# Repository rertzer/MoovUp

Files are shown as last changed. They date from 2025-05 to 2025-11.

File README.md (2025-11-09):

# MoovUp

MoovUp is a 3D printed robotic arm based on the [InMoov](inmoov.fr) project.
Mounted on a wooden crate, it has eight degrees of freedom and each finger is equipped with a pressure sensor.
The thumb's position has been redesigned to give a grasping function.
The arm is driven by an ATMega2560 microcontroler programmed in bare-metal C++.
Communication and control are implemented via a UART serial interface.

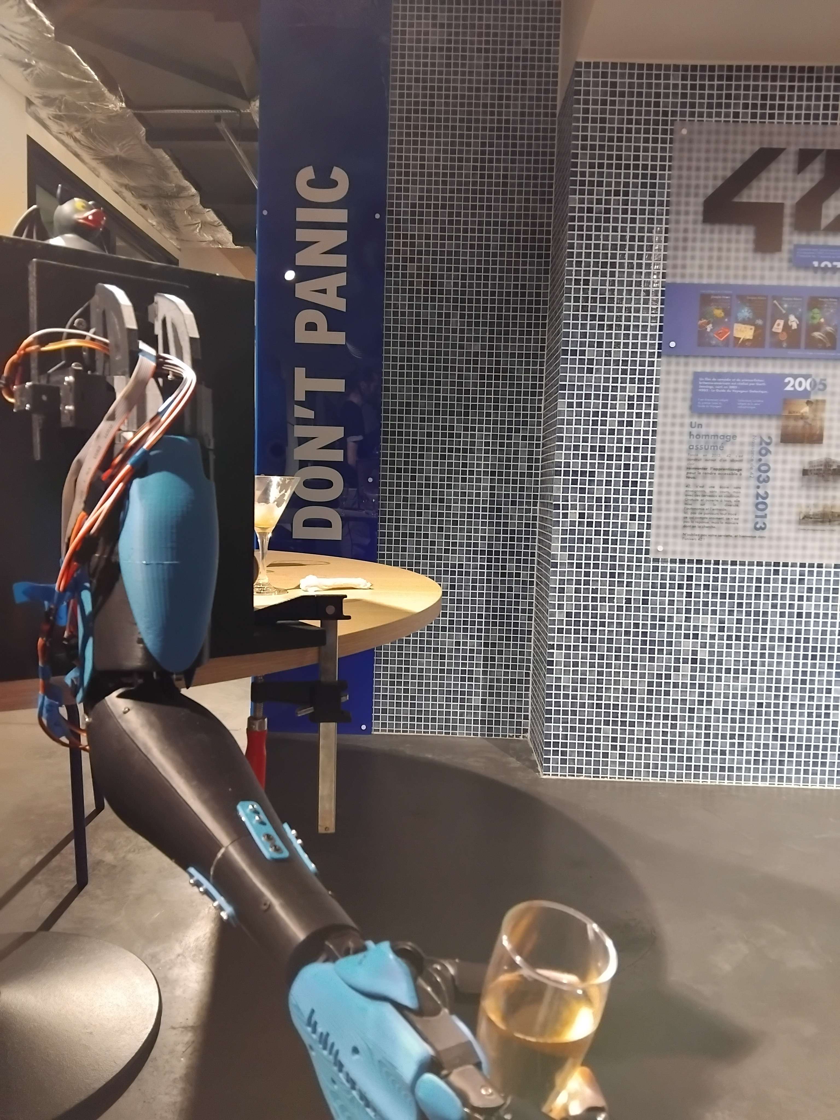
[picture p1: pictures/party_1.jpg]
MoovUp toasting


# UART Commands

- shoulder left
- shoulder right
- wrist left
- wrist right
- hand open
- hand close
- hand grab
- thumb open
- thumb close
- index open
- index close
- finger open

# pinout

| ArduinoMega pin | ATmega 2560 port | timer | kind | usage |
| :---: | :---: | :---: | :----- | :--- |
| A1 | PF1 |  -- | sensor | thumb |
| A2 | PF2 |  -- | sensor | index |
| A3 | PF3 |  -- | sensor | middle |
| A4 | PF4 |  -- | sensor | ring |
| A5 | PF5 |  -- | sensor | pinky |
| D2 | PE4 | OC3B  | motor  | thumb |
| D3 | PE5 | OC3C  | motor  | index |
| D5 | PE3 | OC3A  | motor  | middle |
| D6 | PH3 | OC4A  | motor  | ring |
| D7 | PH4 | OC4B  | motor  | pinky |
| D8 | PH5 | OC4C  | motor  | wrist |
| D11 | PB5 | OC1A  | motor  | elbow |
| D12 | PB6 | OC1B  | motor  | shoulder |

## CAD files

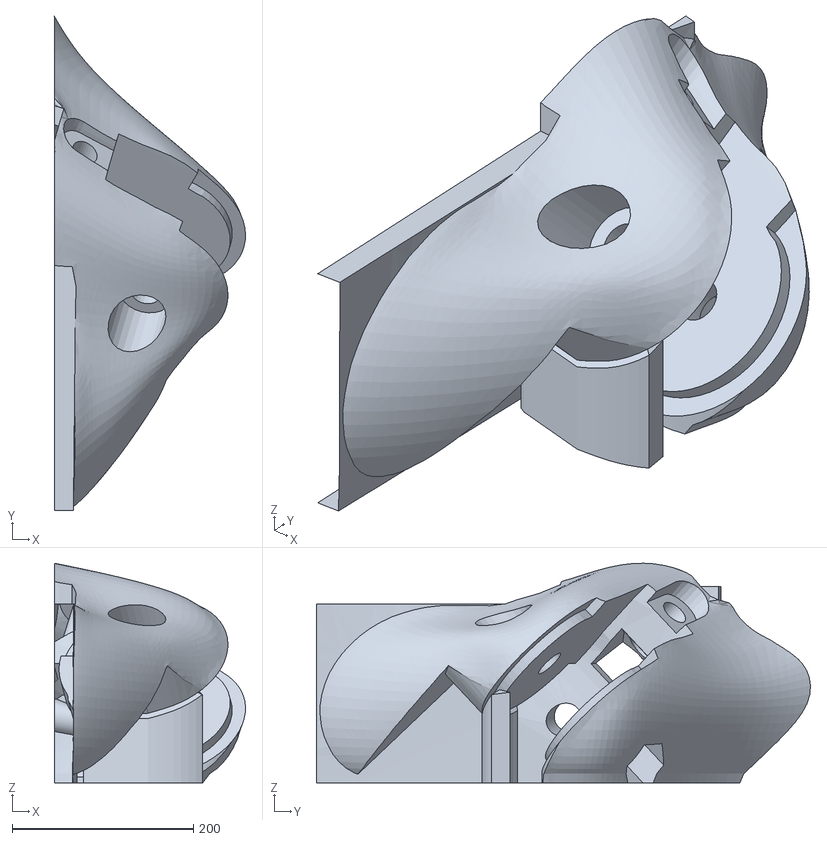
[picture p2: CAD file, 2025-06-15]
fusion_models/blender/thumb.stl
210.6 x 544.6 x 242.1

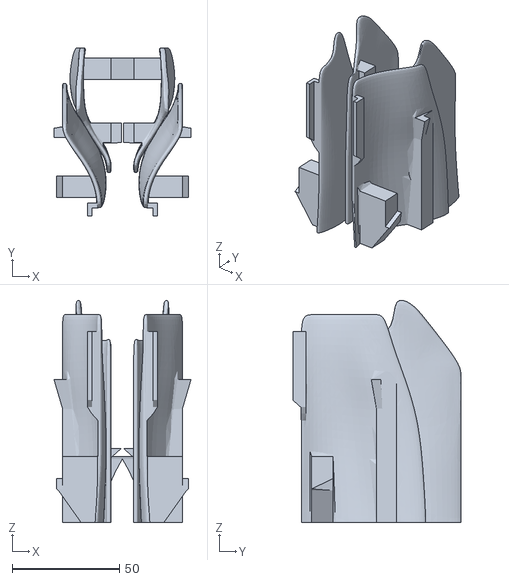
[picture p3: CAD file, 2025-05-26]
toPrint/bicep/color/armtopcover3.stl
63.9 x 78.6 x 103.5

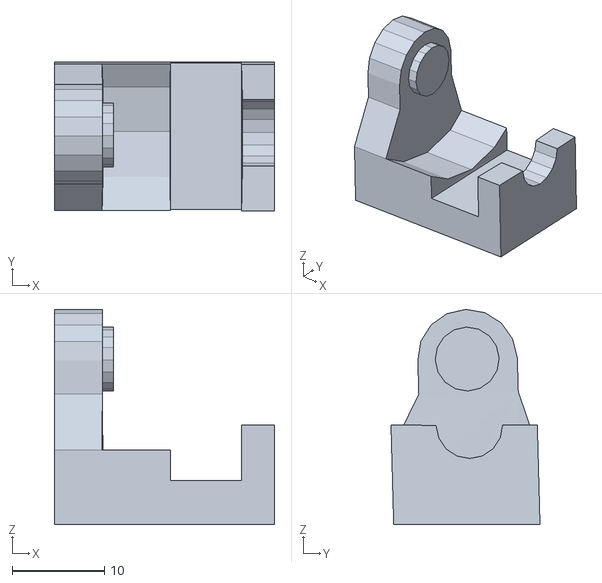
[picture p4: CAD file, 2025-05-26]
toPrint/bicep/GearHolderV1.stl
23.9 x 16.2 x 23.4

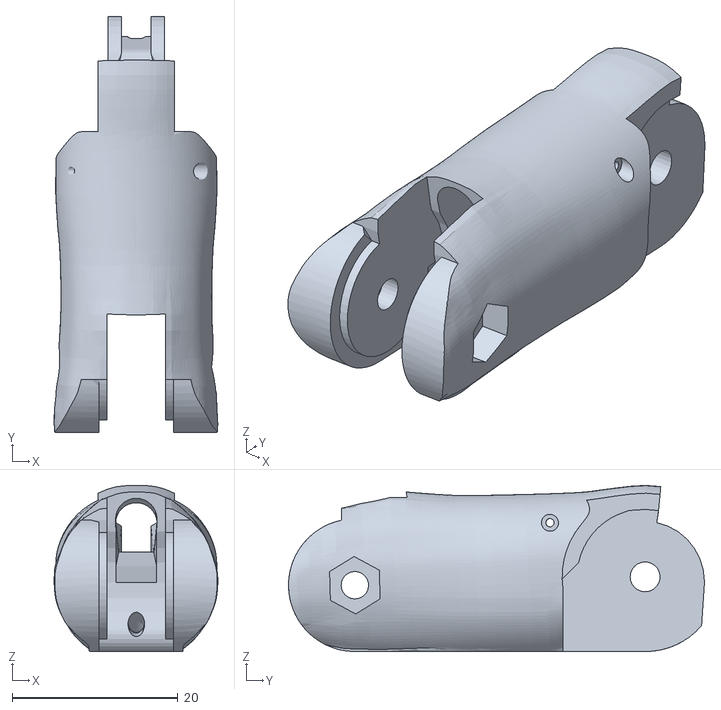
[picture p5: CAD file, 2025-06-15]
toPrint/extra/thumb.stl
19.7 x 50.1 x 20.0

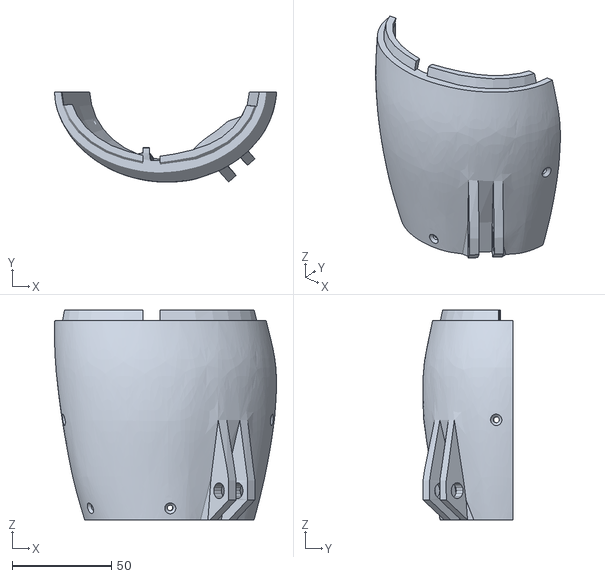
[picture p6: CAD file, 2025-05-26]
toPrint/forarm/robpart4V4.stl
111.8 x 45.5 x 105.6

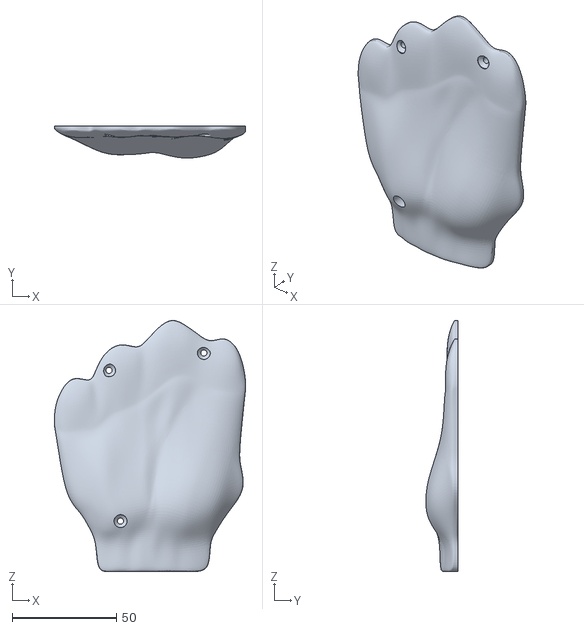
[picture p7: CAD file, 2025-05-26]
toPrint/hand/color/i2_PalmCoverV2.stl
92.0 x 15.5 x 120.7

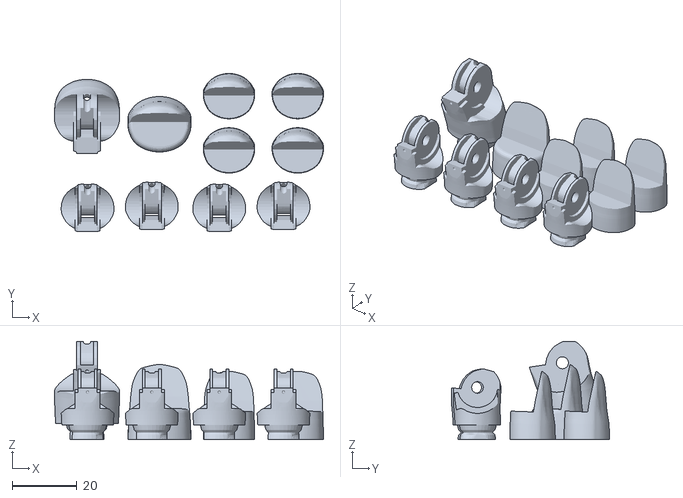
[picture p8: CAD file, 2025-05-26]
toPrint/hand/i2_FingersTipX5V2.stl
82.9 x 48.7 x 30.2

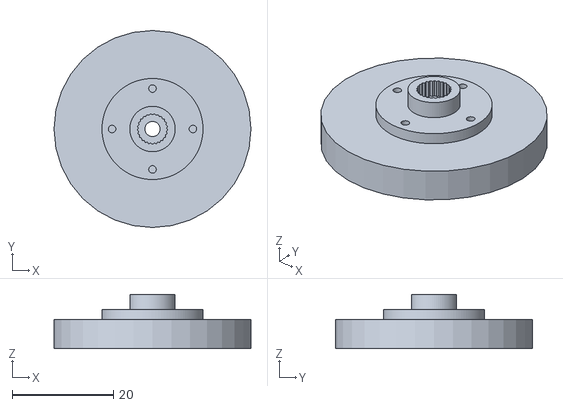
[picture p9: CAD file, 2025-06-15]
toPrint/motor/servoDisk.stl
39.0 x 39.0 x 10.7

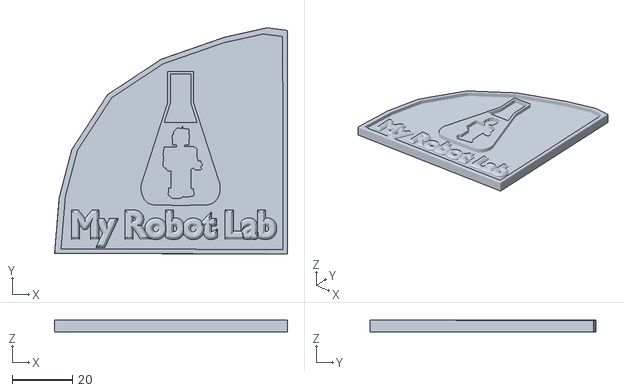
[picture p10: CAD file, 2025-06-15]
toPrint/shoulder/color/LogoRightMyrobotlabV2.stl
77.1 x 74.9 x 4.11

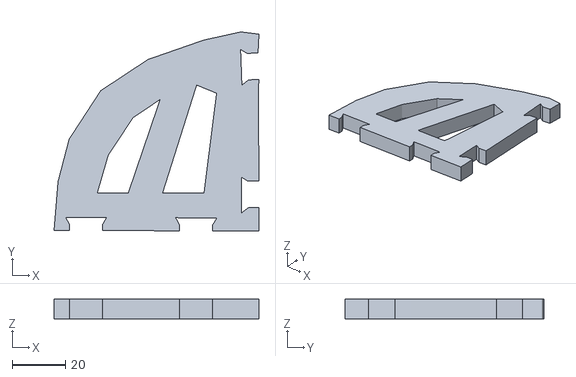
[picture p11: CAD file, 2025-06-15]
toPrint/shoulder/PivConnectorV1.stl
77.1 x 74.9 x 7.49

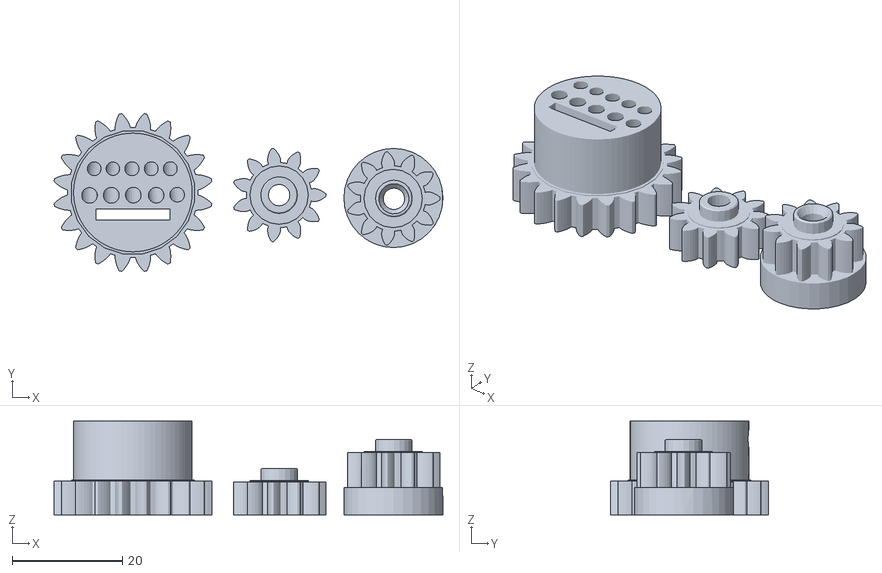
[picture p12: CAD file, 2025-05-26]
toPrint/wrist/WristGearsV5.stl
70.7 x 28.7 x 17.1

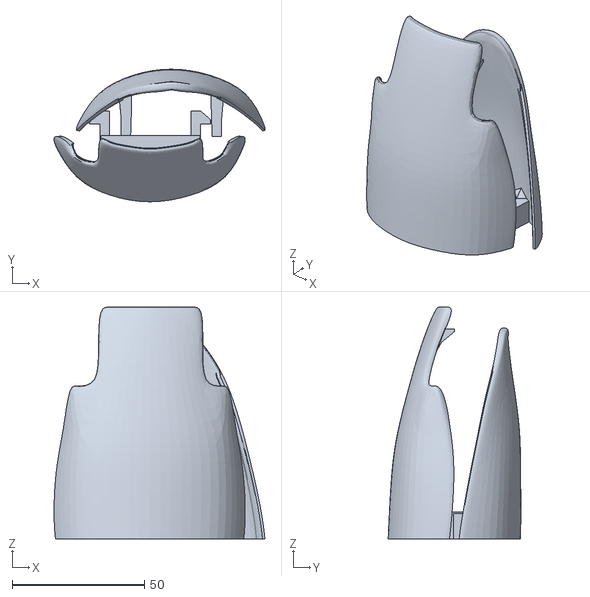
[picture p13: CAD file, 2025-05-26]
toPrint/bicep/color/armtopcover2.stl
79.7 x 50.2 x 87.7

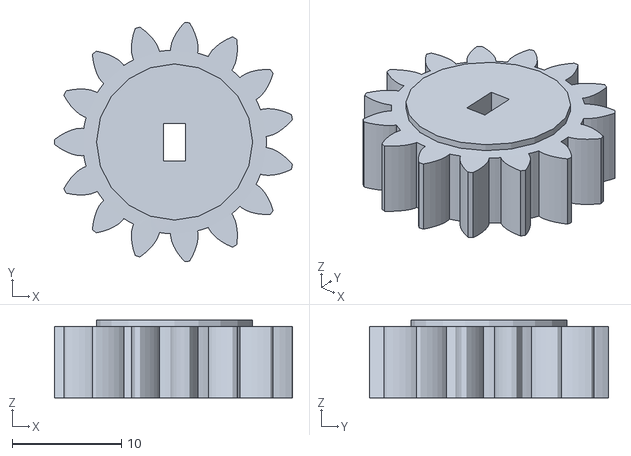
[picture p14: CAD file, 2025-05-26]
toPrint/bicep/gearpotentioV1.stl
21.8 x 22.0 x 7.15

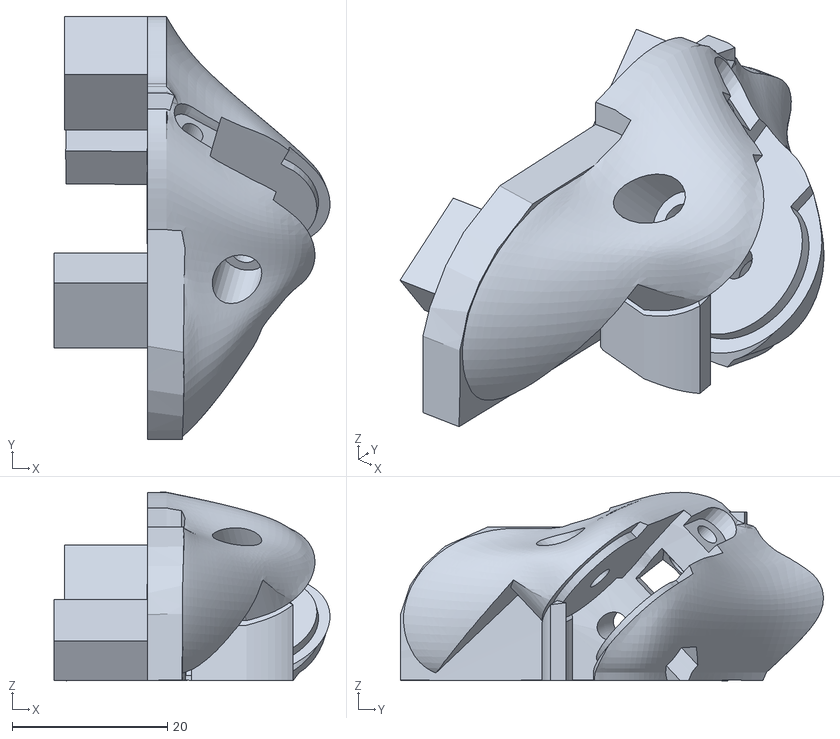
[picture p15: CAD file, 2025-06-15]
toPrint/extra/thumbBase.stl
35.5 x 54.5 x 24.3

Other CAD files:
toPrint/forarm/robpart2V4.stl
toPrint/hand/i2_WristLargeV2.stl
toPrint/motor/motorAdaptor.stl
toPrint/shoulder/color/LogoLeftMyrobotlabV2.stl
fusion_models/Copy_v4.f3d
fusion_models/blender/servoDisk.blend
fusion_models/blender/servoDiskShoulder.blend
fusion_models/blender/thumb2.blend
fusion_models/blender/thumb3.blend
fusion_models/perso_v6.f3d
fusion_models/socle.f3d
fusion_models/test2 v3.f3d
fusion_models/thumb.f3d
toPrint/bicep/HighArmSideV3.stl
toPrint/bicep/LowArmSideV3.stl
toPrint/bicep/PistonanticlockV2.stl
toPrint/bicep/PistonbaseantiV2.stl
toPrint/bicep/PivPotentioRoundV3.stl
toPrint/bicep/PivPotentioSquareV3.stl
toPrint/bicep/ReinforcerV2.stl
toPrint/bicep/RibonPusherV1.stl
toPrint/bicep/RotGearV6.stl
toPrint/bicep/RotMitV3.stl
toPrint/bicep/RotTitV4.stl
toPrint/bicep/RotWormV5.stl
toPrint/bicep/RotcenterV3.stl
toPrint/bicep/armtopcover1.stl
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

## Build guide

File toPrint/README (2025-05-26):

Imprimer d'abord la main et l'avant bras. Le biceps peut être fait plus tard.
Dans les dossiers COLOR, ce sont des pièces décoratives. Elles peuvent être imprimées plus tard. Ce serait bien de pouvoir les faire en couleur (blanc, vert ou jaune selon disponibilité).
Certaines pièces (le pouce notamment) vont nécessiter des modifs. Il y aura certainement besoin de les tester/réimprimer plusieurs fois.
Merci beaucoup :)

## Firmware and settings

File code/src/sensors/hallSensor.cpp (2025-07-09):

/* ************************************************************************** */
/*                                                                            */
/*                                                        :::      ::::::::   */
/*   hallSensor.cpp                                     :+:      :+:    :+:   */
/*                                                    +:+ +:+         +:+     */
/*   By: fguarrac <fguarrac@student.42.fr>          +#+  +:+       +#+        */
/*                                                +#+#+#+#+#+   +#+           */
/*   Created: 2025/04/02 16:21:12 by fguarrac          #+#    #+#             */
/*   Updated: 2025/06/15 01:06:44 by fguarrac         ###   ########.fr       */
/*                                                                            */
/* ************************************************************************** */

#include "hallSensor.hpp"
uint8_t g_pinToPort[] = {
	PE,	 // PE 0 ** 0 ** USART0_RX
	PE,	 // PE 1 ** 1 ** USART0_TX
	PE,	 // PE 4 ** 2 ** PWM2
	PE,	 // PE 5 ** 3 ** PWM3
	PG,	 // PG 5 ** 4 ** PWM4
	PE,	 // PE 3 ** 5 ** PWM5
	PH,	 // PH 3 ** 6 ** PWM6
	PH,	 // PH 4 ** 7 ** PWM7
	PH,	 // PH 5 ** 8 ** PWM8
	PH,	 // PH 6 ** 9 ** PWM9
	PB,	 // PB 4 ** 10 ** PWM10
	PB,	 // PB 5 ** 11 ** PWM11
	PB,	 // PB 6 ** 12 ** PWM12
	PB,	 // PB 7 ** 13 ** PWM13
	PJ,	 // PJ 1 ** 14 ** USART3_TX
	PJ,	 // PJ 0 ** 15 ** USART3_RX
	PH,	 // PH 1 ** 16 ** USART2_TX
	PH,	 // PH 0 ** 17 ** USART2_RX
	PD,	 // PD 3 ** 18 ** USART1_TX
	PD,	 // PD 2 ** 19 ** USART1_RX
	PD,	 // PD 1 ** 20 ** I2C_SDA
	PD,	 // PD 0 ** 21 ** I2C_SCL
	PA,	 // PA 0 ** 22 ** D22
	PA,	 // PA 1 ** 23 ** D23
	PA,	 // PA 2 ** 24 ** D24
	PA,	 // PA 3 ** 25 ** D25
	PA,	 // PA 4 ** 26 ** D26
	PA,	 // PA 5 ** 27 ** D27
	PA,	 // PA 6 ** 28 ** D28
	PA,	 // PA 7 ** 29 ** D29
	PC,	 // PC 7 ** 30 ** D30
	PC,	 // PC 6 ** 31 ** D31
	PC,	 // PC 5 ** 32 ** D32
	PC,	 // PC 4 ** 33 ** D33
	PC,	 // PC 3 ** 34 ** D34
	PC,	 // PC 2 ** 35 ** D35
	PC,	 // PC 1 ** 36 ** D36
	PC,	 // PC 0 ** 37 ** D37
	PD,	 // PD 7 ** 38 ** D38
	PG,	 // PG 2 ** 39 ** D39
	PG,	 // PG 1 ** 40 ** D40
	PG,	 // PG 0 ** 41 ** D41
	PL,	 // PL 7 ** 42 ** D42
	PL,	 // PL 6 ** 43 ** D43
	PL,	 // PL 5 ** 44 ** D44
	PL,	 // PL 4 ** 45 ** D45
	PL,	 // PL 3 ** 46 ** D46
	PL,	 // PL 2 ** 47 ** D47
	PL,	 // PL 1 ** 48 ** D48
	PL,	 // PL 0 ** 49 ** D49
	PB,	 // PB 3 ** 50 ** SPI_MISO
	PB,	 // PB 2 ** 51 ** SPI_MOSI
	PB,	 // PB 1 ** 52 ** SPI_SCK
	PB,	 // PB 0 ** 53 ** SPI_SS
	PF,	 // PF 0 ** 54 ** A0
	PF,	 // PF 1 ** 55 ** A1
	PF,	 // PF 2 ** 56 ** A2
	PF,	 // PF 3 ** 57 ** A3
	PF,	 // PF 4 ** 58 ** A4
	PF,	 // PF 5 ** 59 ** A5
	PF,	 // PF 6 ** 60 ** A6
	PF,	 // PF 7 ** 61 ** A7
	PK,	 // PK 0 ** 62 ** A8
	PK,	 // PK 1 ** 63 ** A9
	PK,	 // PK 2 ** 64 ** A10
	PK,	 // PK 3 ** 65 ** A11
	PK,	 // PK 4 ** 66 ** A12
	PK,	 // PK 5 ** 67 ** A13
	PK,	 // PK 6 ** 68 ** A14
	PK	 // PK 7 ** 69 ** A15
};
uint8_t g_pinToBit[] = {
	_BV(0),	 // PE 0 ** 0 ** USART0_RX
	_BV(1),	 // PE 1 ** 1 ** USART0_TX
	_BV(4),	 // PE 4 ** 2 ** PWM2
	_BV(5),	 // PE 5 ** 3 ** PWM3
	_BV(5),	 // PG 5 ** 4 ** PWM4
	_BV(3),	 // PE 3 ** 5 ** PWM5
	_BV(3),	 // PH 3 ** 6 ** PWM6
	_BV(4),	 // PH 4 ** 7 ** PWM7
	_BV(5),	 // PH 5 ** 8 ** PWM8
	_BV(6),	 // PH 6 ** 9 ** PWM9
	_BV(4),	 // PB 4 ** 10 ** PWM10
	_BV(5),	 // PB 5 ** 11 ** PWM11
	_BV(6),	 // PB 6 ** 12 ** PWM12
	_BV(7),	 // PB 7 ** 13 ** PWM13
	_BV(1),	 // PJ 1 ** 14 ** USART3_TX
	_BV(0),	 // PJ 0 ** 15 ** USART3_RX
	_BV(1),	 // PH 1 ** 16 ** USART2_TX
	_BV(0),	 // PH 0 ** 17 ** USART2_RX
	_BV(3),	 // PD 3 ** 18 ** USART1_TX
	_BV(2),	 // PD 2 ** 19 ** USART1_RX
	_BV(1),	 // PD 1 ** 20 ** I2C_SDA
	_BV(0),	 // PD 0 ** 21 ** I2C_SCL
	_BV(0),	 // PA 0 ** 22 ** D22
	_BV(1),	 // PA 1 ** 23 ** D23
	_BV(2),	 // PA 2 ** 24 ** D24
	_BV(3),	 // PA 3 ** 25 ** D25
	_BV(4),	 // PA 4 ** 26 ** D26
	_BV(5),	 // PA 5 ** 27 ** D27
	_BV(6),	 // PA 6 ** 28 ** D28
	_BV(7),	 // PA 7 ** 29 ** D29
	_BV(7),	 // PC 7 ** 30 ** D30
	_BV(6),	 // PC 6 ** 31 ** D31
	_BV(5),	 // PC 5 ** 32 ** D32
	_BV(4),	 // PC 4 ** 33 ** D33
	_BV(3),	 // PC 3 ** 34 ** D34
	_BV(2),	 // PC 2 ** 35 ** D35
	_BV(1),	 // PC 1 ** 36 ** D36
	_BV(0),	 // PC 0 ** 37 ** D37
	_BV(7),	 // PD 7 ** 38 ** D38
	_BV(2),	 // PG 2 ** 39 ** D39
	_BV(1),	 // PG 1 ** 40 ** D40
	_BV(0),	 // PG 0 ** 41 ** D41
	_BV(7),	 // PL 7 ** 42 ** D42
	_BV(6),	 // PL 6 ** 43 ** D43
	_BV(5),	 // PL 5 ** 44 ** D44
	_BV(4),	 // PL 4 ** 45 ** D45
	_BV(3),	 // PL 3 ** 46 ** D46
	_BV(2),	 // PL 2 ** 47 ** D47
	_BV(1),	 // PL 1 ** 48 ** D48
	_BV(0),	 // PL 0 ** 49 ** D49
	_BV(3),	 // PB 3 ** 50 ** SPI_MISO
	_BV(2),	 // PB 2 ** 51 ** SPI_MOSI
	_BV(1),	 // PB 1 ** 52 ** SPI_SCK
	_BV(0),	 // PB 0 ** 53 ** SPI_SS
	_BV(0),	 // PF 0 ** 54 ** A0
	_BV(1),	 // PF 1 ** 55 ** A1
	_BV(2),	 // PF 2 ** 56 ** A2
	_BV(3),	 // PF 3 ** 57 ** A3
	_BV(4),	 // PF 4 ** 58 ** A4
	_BV(5),	 // PF 5 ** 59 ** A5
	_BV(6),	 // PF 6 ** 60 ** A6
	_BV(7),	 // PF 7 ** 61 ** A7
	_BV(0),	 // PK 0 ** 62 ** A8
	_BV(1),	 // PK 1 ** 63 ** A9
	_BV(2),	 // PK 2 ** 64 ** A10
	_BV(3),	 // PK 3 ** 65 ** A11
	_BV(4),	 // PK 4 ** 66 ** A12
	_BV(5),	 // PK 5 ** 67 ** A13
	_BV(6),	 // PK 6 ** 68 ** A14
	_BV(7)	 // PK 7 ** 69 ** A15
};
uint16_t g_portToMode[] = {NOT_A_PORT,		(uint16_t)&DDRA, (uint16_t)&DDRB, (uint16_t)&DDRC, (uint16_t)&DDRD,
						   (uint16_t)&DDRE, (uint16_t)&DDRF, (uint16_t)&DDRG, (uint16_t)&DDRH, NOT_A_PORT,
						   (uint16_t)&DDRJ, (uint16_t)&DDRK, (uint16_t)&DDRL};

uint16_t g_portToOutput[] = {NOT_A_PORT,	   (uint16_t)&PORTA, (uint16_t)&PORTB, (uint16_t)&PORTC, (uint16_t)&PORTD,
							 (uint16_t)&PORTE, (uint16_t)&PORTF, (uint16_t)&PORTG, (uint16_t)&PORTH, NOT_A_PORT,
							 (uint16_t)&PORTJ, (uint16_t)&PORTK, (uint16_t)&PORTL};

Hall::Hall(uint8_t pin) : _pin(pin) {
	this->_init();
}

Hall::Hall(Hall const& src) : _pin(src.getPin()) {}

Hall& Hall::operator=(Hall const& src) {
	if (this != &src)
		this->_pin = src.getPin();
	return (*this);
}

Hall::~Hall(void) {}

uint8_t Hall::getPin(void) const {
	return (this->_pin);
}

void Hall::_init(void) {
	//	Set port
	uint8_t bit = *g_pinToBit + this->_pin;
	uint8_t port = *g_pinToPort + this->_pin;

	uint8_t* reg = (uint8_t*)(*g_portToMode + port);
	uint8_t* out = (uint8_t*)(*g_portToOutput + port);

	uint8_t oldSREG = SREG;
	cli();
	*reg &= ~bit;
	*out &= ~bit;
	SREG = oldSREG;

	//	Init ADC
	uint8_t pinTmp = this->_pin;
	if (pinTmp >= 54)
		pinTmp -= 54;

	//	//	Set port
	//	DDRF &= ~(1u << DDF0);	   //	Set pin A0 as input (Port F 0)
	//	PORTF &= ~(1u << PORTF0);  //	Disable pull up resistor

	//	Init ADC
	ADMUX |= (1u << REFS0);	  //	Set AVcc as reference
	ADCSRA |= (1u << ADPS0);  //	Set prescaler to 128
	ADCSRA |= (1u << ADPS1);  //	Set prescaler to 128
	ADCSRA |= (1u << ADPS2);  //	Set prescaler to 128
	ADCSRA |= (1u << ADEN);	  //	Enable ADC

	//	Dummy run for ADC initialisation
	ADCSRA |= (1u << ADSC);	 //	Start conversion
	_delay_ms(10);			 //	First conversion may take some time
	while (ADCSRA & (1u << ADSC))
		;		//	Wait for ADC to finish conversion
	(void)ADC;	//	Read conversion
}

uint16_t Hall::readValue(void) const {
	//	Wait for some conversion to finish (ADIF in ADCSRA) or check ADSC in ADCSRA?	///	Some other finger already
	// may be reading the ADC
	while (!(ADCSRA & (1u << ADIF)))
		;  //	Wait for conversion to finish
		   //	while (ADCSRA & (1u << ADSC))
		   //		;  							//	Wait for conversion to finish
	//	Set ADC's input
	if (this->_pin > 7)			   //	If ADC input > ADC7
		ADCSRB |= (1u << MUX5);	   //	Set MUX5
	ADMUX &= 0xF8;				   //	Clear previous ADC input
	ADMUX |= (this->_pin & 0x07);  //	Select new ADC input
	//	Start converson
	ADCSRA |= (1u << ADSC);	 //	Start conversion
	//	Wait for conversion to finish
	while (ADCSRA & (1u << ADSC))
		;  //	Wait for conversion to finish
	//	Return read value
	return (ADC);
}
/*
static void ft_itoaptr(uint16_t conv, char* ptr) {
	uint16_t convTmp;
	uint8_t	 convLen;

	convLen = 1;
	convTmp = conv;
	while (convTmp /= 10)
		++convLen;
	ptr[convLen--] = '\0';
	if (conv == 0)
		ptr[convLen] = '0';
	while (conv > 0) {
		ptr[convLen--] = (conv % 10) + '0';
		conv /= 10;
	}
}

int main(void) {
	uint16_t	conv;
	char		digital[6];  //	Max value = 65535 + '\0'
	Uart		uart;
	Hall		hall(A0);

//	//	Init
//
//	//	Set port
//	DDRF &= ~(1u << DDF0);	   //	Set pin A0 as input (Port F 0)
//	PORTF &= ~(1u << PORTF0);  //	Disable pull up resistor
//
	uart.init();

	//	Init ADC
//	ADMUX |= (1u << REFS0);	  //	Set AVcc as reference
//	ADCSRA |= (1u << ADEN);	  //	Enable ADC
//	ADCSRA |= (1u << ADPS0);  //	Set prescaler to 128
//	ADCSRA |= (1u << ADPS1);  //	Set prescaler to 128
//	ADCSRA |= (1u << ADPS2);  //	Set prescaler to 128
//
//	DIDR0 |= (1u << ADC1D) | (1u << ADC2D) | (1u << ADC3D) | (1u << ADC4D) | (1u << ADC5D) | (1u << ADC6D) |
//			 (1u << ADC7D);	 //	Disable unused ADC inputs
//	DIDR1 |= (1u << ADC8D) | (1u << ADC9D) | (1u << ADC10D) | (1u << ADC11D) | (1u << ADC12D) | (1u << ADC13D) |
//			 (1u << ADC14D) | (1u << ADC14D);  //	Disable unused ADC inputs
//
//	//	Dummy run for ADC initialisation
//	ADCSRA |= (1u << ADSC);	 //	Start conversion
//	_delay_ms(10);			 //	First conversion may take some time
//	while (ADCSRA & (1u << ADSC))
//		;		 //	Wait for ADC to finish conversion
//	conv = ADC;	 //	Read conversion

	//	Loop

	for (;;) {
		//ADCSRA |= (1u << ADSC);	 //	Start conversion
		//while (ADCSRA & (1u << ADSC))
		//	;  //	Wait for conversion to finish
		//conv = ADC;
		conv = hall.readValue();
		ft_itoaptr(conv, digital);
		uart.printstrnl(digital);
		_delay_ms(20);
	}
}
*/

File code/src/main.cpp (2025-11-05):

#include <util/delay.h>

#include "Arm.hpp"
#include "Motor.hpp"
#include "MotorCheck.hpp"
#include "SensorCalibrate.hpp"
#include "Uart.hpp"

extern Uart uart;
Uart		uart;

int main() {
	uart.init();

	Motor::MotorsInit();
	Arm arm;
	arm.reset();
	arm.moveTrough();
	_delay_ms(2000);

	MotorCheck motorcheck(arm);
	motorcheck.run();

	SensorCalibrate sensorcalibrate(arm);
	uint8_t			error = sensorcalibrate.calibrate();
	if (error) {
		uart.printstrnl("sensor calibration error...");
		_delay_ms(2000);
	}

	uart.printstr("MoovUp ready\r\n");
	while (true) {
		uart.printstr("Waiting for instructions...\r\n");
		uart.readline();
		uart.printline();

		arm.exec(uart.getline());
		arm.moveTrough();

		_delay_ms(60);
	}
	return (0);
};

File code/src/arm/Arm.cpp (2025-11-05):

#include "Arm.hpp"
#include <string.h>
#include "Uart.hpp"

extern Uart uart;

void Arm::move() {
	elbow.move();
	index.move();
	middle.move();
	pinky.move();
	ring.move();
	shoulder.move();
	thumb.move();
	wrist.move();
}

void Arm::moveTrough() {
	for (int i = 0; i < 250; ++i) {
		move();
		_delay_ms(20);
	}
}

void Arm::setSpeed(uint16_t s) {
	elbow.setSpeed(s);
	index.setSpeed(s);
	middle.setSpeed(s);
	pinky.setSpeed(s);
	ring.setSpeed(s);
	shoulder.setSpeed(s);
	thumb.setSpeed(s);
	wrist.setSpeed(s);
}

void Arm::reset() {
	elbow.reset();
	index.reset();
	middle.reset();
	pinky.reset();
	ring.reset();
	shoulder.reset();
	thumb.reset();
	wrist.reset();
	setSpeed(12);
}

void Arm::exec(char* line) {
	if (strcmp("shoulder left", line) == 0) {
		shoulderLeft();
	} else if (strcmp("shoulder right", line) == 0) {
		shoulderRight();
	} else if (strcmp("shoulder left", line) == 0) {
		shoulderLeft();
	} else if (strcmp("wrist left", line) == 0) {
		wristLeft();
	} else if (strcmp("wrist right", line) == 0) {
		wristRight();
	} else if (strcmp("hand open", line) == 0) {
		handOpen();
	} else if (strcmp("hand close", line) == 0) {
		handClose();
	} else if (strcmp("hand grab", line) == 0) {
		handGrab();
	} else if (strcmp("finger open", line) == 0) {
		fingerOpen();
	} else if (strcmp("finger close", line) == 0) {
		fingerClose();
	} else if (strcmp("index open", line) == 0) {
		indexOpen();
	} else if (strcmp("index close", line) == 0) {
		indexClose();
	}
}
void Arm::shoulderLeft() {
	shoulder.setTarget(80);
	uart.printstrnl("sl");
}
void Arm::shoulderRight() {
	shoulder.setTarget(0);
}
void Arm::wristLeft() {
	wrist.setTarget(180);
}
void Arm::wristRight() {
	wrist.setTarget(000);
}
void Arm::handOpen() {
	index.setTarget(0);
	middle.setTarget(0);
	ring.setTarget(0);
	pinky.setTarget(0);
}
void Arm::handClose() {
	index.setTarget(180);
	middle.setTarget(180);
	ring.setTarget(180);
	pinky.setTarget(180);
}
void Arm::handGrab() {
	uart.printstrnl("hg");
}
void Arm::thumbOpen() {
	thumb.setTarget(0);
}

void Arm::thumbClose() {
	thumb.setTarget(180);
}

void Arm::indexOpen() {
	index.setTarget(0);
}
void Arm::indexClose() {
	index.setTarget(180);
}
void Arm::fingerOpen() {
	index.setTarget(0);
	middle.setTarget(0);
	ring.setTarget(0);
	pinky.setTarget(0);
}
void Arm::fingerClose() {
	index.setTarget(180);
	middle.setTarget(180);
	ring.setTarget(180);
	pinky.setTarget(0);
}

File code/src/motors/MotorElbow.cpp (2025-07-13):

#include "MotorElbow.hpp"

/* For Arduino Mega, ATmega2560
 * using timer OC1A and pin D11 (PB5)
 */

MotorElbow::MotorElbow(uint16_t start_pos) {
	// connected, non-inverted
	TCCR1A |= (1 << COM1A1);
	TCCR1A &= ~(1 << COM1A0);

	// initial position
	OCR1A = start_pos;

	// set pin as output
	DDRB |= (1 << PB5);
}

MotorElbow::MotorElbow(MotorElbow const& m) : Motor() {
	(void)m;
}

MotorElbow::~MotorElbow() {
	// disconnect
	TCCR1A &= ~(1 << COM1A1);
	TCCR1A &= ~(1 << COM1A0);

	// unset pin
	DDRB &= ~(1 << PB5);
}

MotorElbow& MotorElbow::operator=(MotorElbow const& m) {
	(void)m;
	return (*this);
}

uint16_t MotorElbow::getPosition() const {
	return ((uint16_t)OCR1A);
}

void MotorElbow::setPosition(uint16_t pos) {
	OCR1A = pos;
}

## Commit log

2025-04-13 Added program architecture + hall effect sensor interfacing code.
2025-04-21 motors Makefile, etc configured
2025-04-25 Added some work in Fusion
    [Copy_v4.f3d, perso_v6.f3d, test2 v3.f3d]
2025-05-06 to print stl files
    [CableHolderWristV5.stl, GearHolderV1.stl, HighArmSideV3.stl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]
2025-05-13 motor code
2025-05-13 to print added forarm files, wrist files put into wrist folder
    [CableHolderWristV5.stl, RobCableBackV3.stl, RobCableFrontV3.stl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]
2025-05-16 fusion360 model for stand
    [socle.f3d]
2025-05-21 hand parts from v1
    [Bolt_entretoise7_deleted_parts v1.f3d]
2025-05-21 added thumb
    [i2_FingersX5V2_thumb v2.f3d]
2025-05-21 moved thumb file into extra¨
    [i2_FingersX5V2_thumb v2.f3d]
2025-05-29 motor head
2025-05-31 wip: code: Motors objects
2025-06-02 cut thumb, need to close the mesh
    [thumb.f3d]
2025-06-02 stl version - cut thumb, need to close the mesh
    [thumb.stl]
2025-06-04 changed entretoise file
    [entretoise.stl]
2025-06-05 thumb base stl first try
    [thumbBase.stl]
2025-06-05 shoulder to print
    [LogoLeftMyrobotlabV2.stl, LogoRightMyrobotlabV2.stl, PivConnectorV1.stl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]
2025-06-06 toPrint thumbBase
    [thumbBase.stl]
2025-06-06 thumbBase.stl face normals recalculated
    [thumbBase.stl]
2025-06-11 3D extra motor
    [motorAdaptor.blend, motorAdaptor.stl, servoDisk.blend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]
2025-06-11 feature: added shoulder motor
2025-06-11 feat: motor thumb and wrist changed start position
2025-06-13 motor stl
    [motorAdaptorBis.stl, servoDiskShoulder.stl]
2025-06-15 blender file
    [servoDiskShoulder.blend]
2025-06-21 feat: moving arm
2025-06-23 feat: elbow and thumb ; arm/... copy constructors
2025-06-29 refactor: added Finger parent class
2025-07-03 refactor arm classes
2025-07-03 build: Makefile : add gnu++11 flag and Joint.cpp as source file
2025-07-06 refactor: Arm parts
2025-07-06 refactor: add Arm class ; move ft_itoa in utils/ft_itoa.cpp
2025-07-13 code: refactor motor
2025-07-13 code:feature: add arm reset
    [Arm.cpp, Index.cpp]
2025-07-14 code: refactor: pwm_min and max ; feat: add MotorCheck procedure
2025-07-14 code: feat: add sensor calibrate routine
2025-07-22 refactor: in arm/... replaced static const by static constexpr
    [Index.cpp, Joint.cpp, Middle.cpp]
2025-11-05 uart command line
2025-11-05 README: added UART commands
